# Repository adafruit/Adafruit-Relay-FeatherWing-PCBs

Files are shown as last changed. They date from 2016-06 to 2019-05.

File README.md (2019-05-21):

## Adafruit Relay FeatherWing PCBs
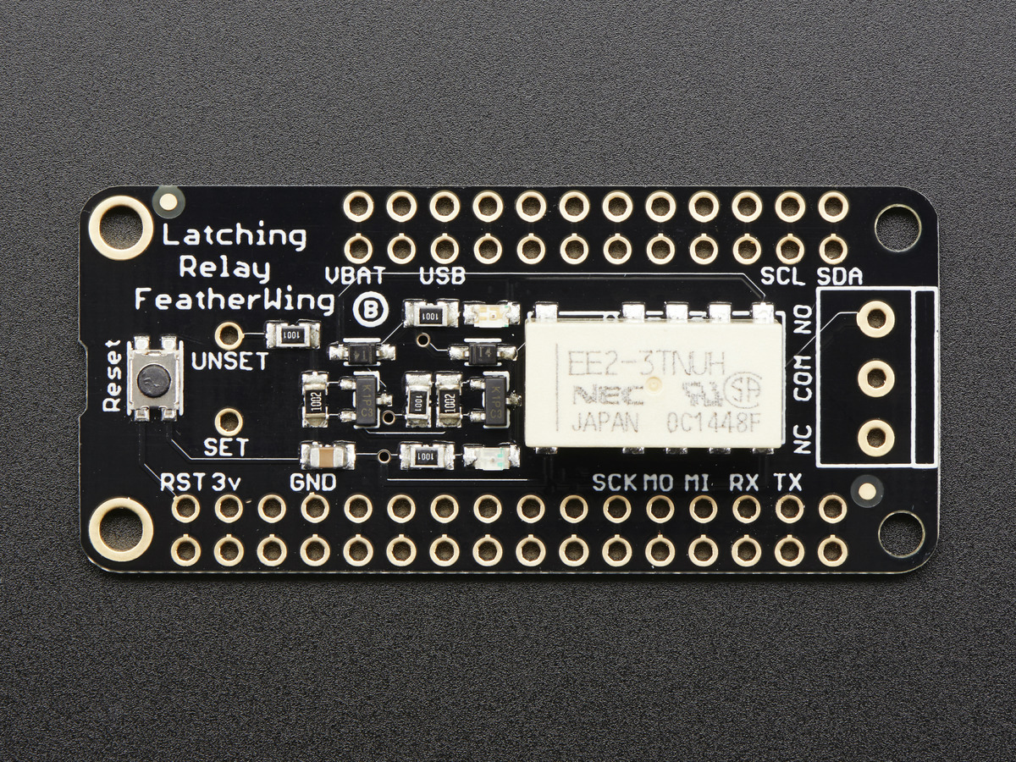
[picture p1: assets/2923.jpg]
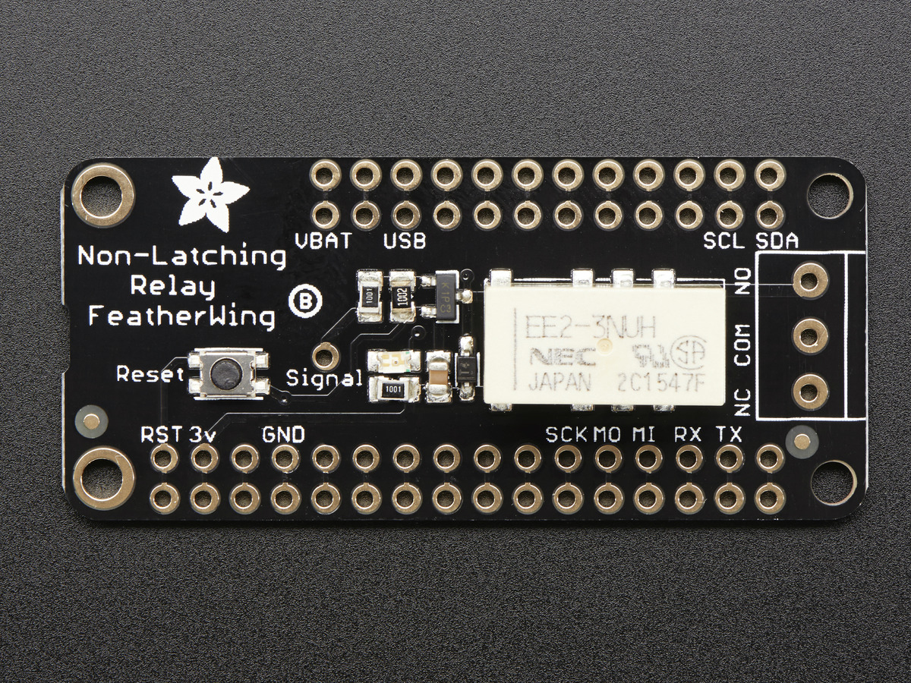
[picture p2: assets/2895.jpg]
&nbsp; <br />
Click to purchase from the Adafruit Shop:
- [Latching Mini Relay FeatherWing](https://www.adafruit.com/product/2923)
- [Non-Latching Mini Relay FeatherWing](https://www.adafruit.com/product/2895)

The are two 'flavors' of these FeatherWings, one is the Latching relay, requires two pins, a SET and UNSET and instead of keeping the SET pin high, you only have to pulse each pin high for 10ms to latch the relay open or closed. You need two pins but save power. Note, if power is lost, the relay will stay in the last setting.

The other type of relay FeatherWing is the simple Non-Latching relay, it requires only a single signal pin.

Both FeatherWings use the same family of relay. You can switch up to 2A of resistive current at 30VDC or ~40VAC or lower. At 110VDC you can switch up to 0.3A, at 120VAC up to 0.5A, and at 250VAC you can switch up to 0.6A. Check the datasheet for the relay for the exact switching capacity, and of course, for reactive/inductive loads you will need to derate. This isn't a relay you can use to turn on and off your washer/dryer, stick to 60W or less. For up to 1200W devices, check out our Power Featherwing which can handle up to 10A!

For more details, check out the product pages at
- https://www.adafruit.com/products/2923
- https://www.adafruit.com/products/2895

This is the PCB files for the Adafruit Relay FeatherWings. The format is EagleCAD schematic and board layout

### License

Adafruit invests time and resources providing this open source design, please support Adafruit and open-source hardware by purchasing products from [Adafruit](https://www.adafruit.com)!

All text above must be included in any redistribution

Designed by Limor Fried/Ladyada for Adafruit Industries.
Creative Commons Attribution/Share-Alike, all text above must be included in any redistribution. 
See license.txt for additional information.

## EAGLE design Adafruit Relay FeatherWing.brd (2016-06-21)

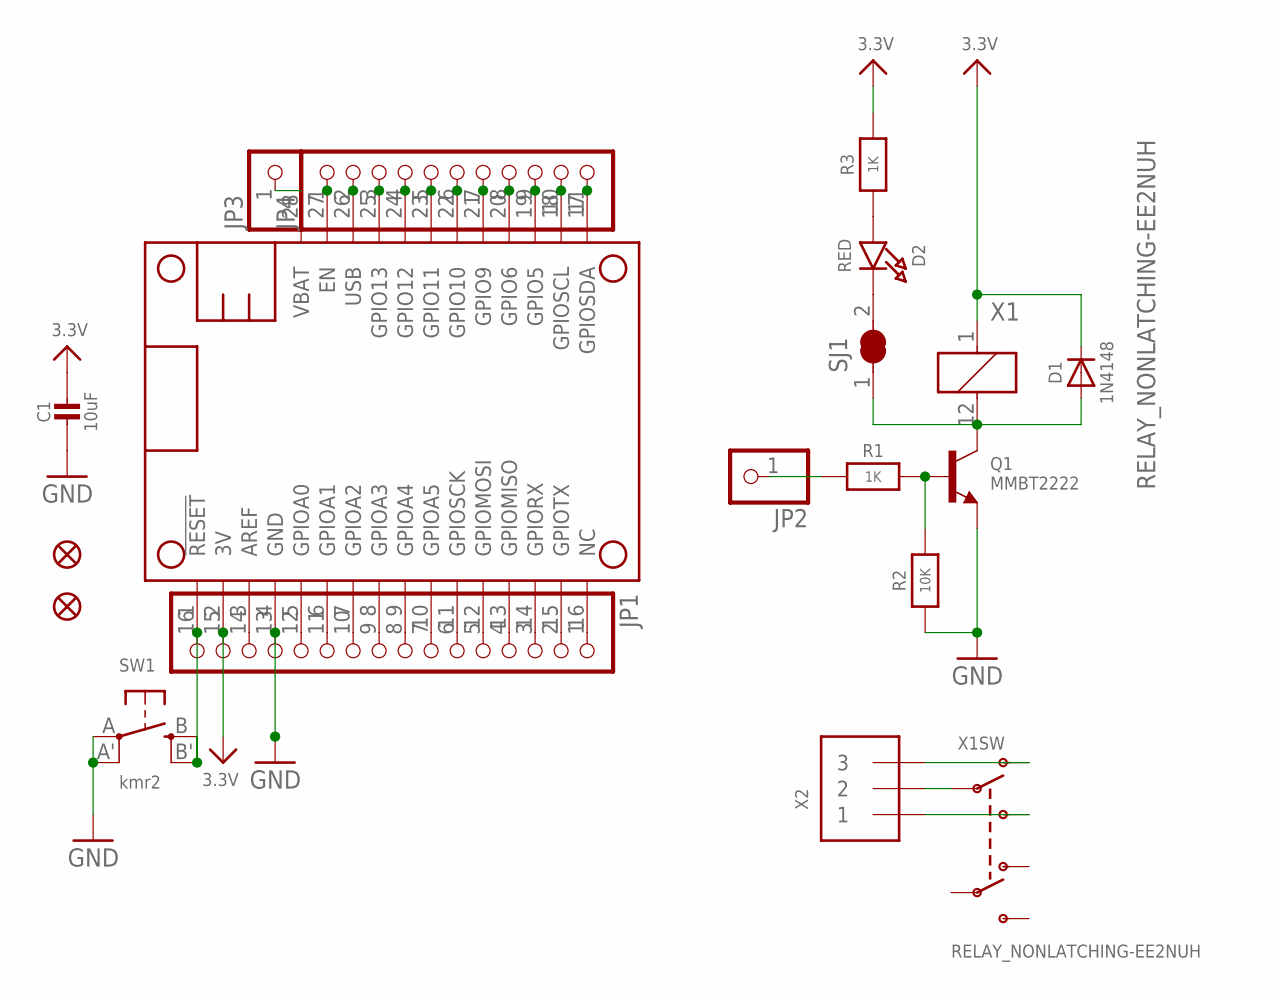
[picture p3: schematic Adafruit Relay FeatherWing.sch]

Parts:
C1: 10uF; 0805-NO
D1: 1N4148; SOD-323
D2: RED; CHIPLED_0805_NOOUTLINE
FID2, FID3: FIDUCIAL""; FIDUCIAL_1MM
JP1: HEADER-1X16ROUND; 1X16_ROUND
JP2, JP3: HEADER-1X1ROUND; 1X01_ROUND
JP4: HEADER-1X11; 1X11_ROUND
MS1: MICROSHIELD
Q1: MMBT2222; SOT23-R
R1, R3: 1K; 0805-NO
R2: 10K; 0805-NO
SJ1: SOLDERJUMPER_CLOSED; SOLDERJUMPER_CLOSEDWIRE
SW1: kmr2; BTN_KMR2_4.6X2.8
X1: RELAY_NONLATCHING-EE2NUH; RELAY_EE2_NOLATCH
X2: TERMBLOCK_1X3; TERMBLOCK_1X3-3.5MM

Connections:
3.3V: C1.1, D1.C, JP1.15, MS1.2 (3V), R3.2, X1.1
COM1: X1.9 (P1), X2.2
GND: C1.2, JP1.13, MS1.4 (GND), Q1.2 (E), R2.1, SW1.A, SW1.A' (P1)
unnamed: D1.A, Q1.3 (C), SJ1.1, X1.12 (2)
unnamed: JP1.1, MS1.16 (NC)
unnamed: JP1.2, MS1.15 (GPIOTX)
unnamed: JP1.3, MS1.14 (GPIORX)
unnamed: JP1.4, MS1.13 (GPIOMISO)
unnamed: JP1.5, MS1.12 (GPIOMOSI)
unnamed: JP1.6, MS1.11 (GPIOSCK)
unnamed: JP1.7, MS1.10 (GPIOA5)
unnamed: JP1.8, MS1.9 (GPIOA4)
unnamed: JP1.9, MS1.8 (GPIOA3)
unnamed: JP1.10, MS1.7 (GPIOA2)
unnamed: JP1.11, MS1.6 (GPIOA1)
unnamed: JP1.12, MS1.5 (GPIOA0)
unnamed: JP4.1, MS1.27 (EN)
unnamed: JP4.3, MS1.25 (GPIO13)
unnamed: JP4.4, MS1.24 (GPIO12)
unnamed: JP4.5, MS1.23 (GPIO11)
unnamed: JP4.6, MS1.22 (GPIO10)
unnamed: JP4.7, MS1.21 (GPIO9)
unnamed: JP4.8, MS1.20 (GPIO6)
unnamed: JP4.9, MS1.19 (GPIO5)
unnamed: Q1.1 (B), R1.2, R2.2
unnamed: JP1.14, MS1.3 (AREF)
unnamed: JP2.1, R1.1
unnamed: D2.C, SJ1.2
unnamed: D2.A, R3.1
unnamed: X1.10 (O1), X2.3
NO1: X1.8 (S1), X2.1
RESET: JP1.16, MS1.1 (!RESET), SW1.B (S), SW1.B' (S1)
SCL: JP4.10, MS1.18 (GPIOSCL)
SDA: JP4.11, MS1.17 (GPIOSDA)
USB: JP4.2, MS1.26 (USB)
VBAT: JP3.1, MS1.28 (VBAT)

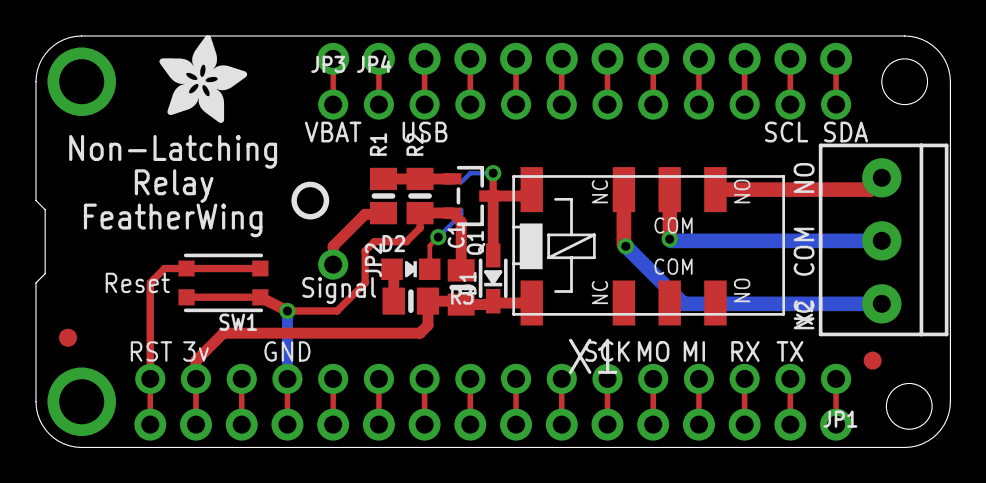
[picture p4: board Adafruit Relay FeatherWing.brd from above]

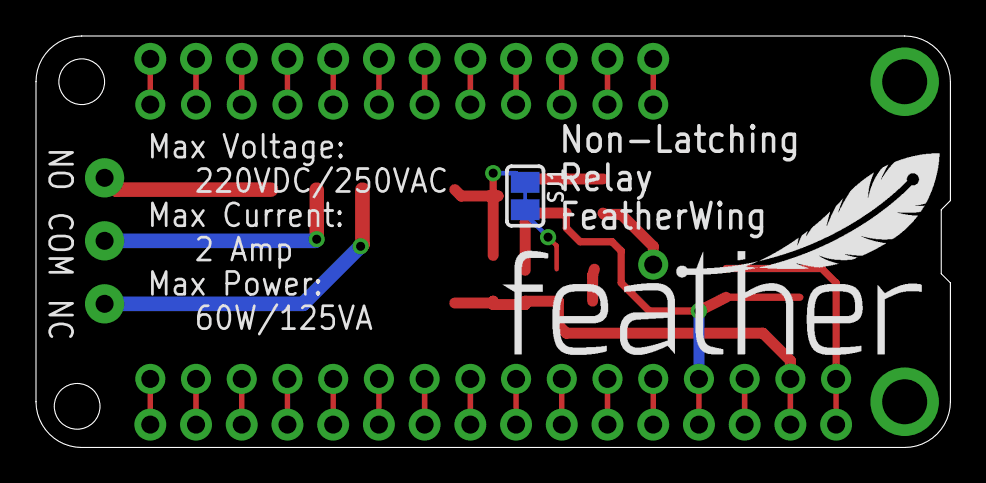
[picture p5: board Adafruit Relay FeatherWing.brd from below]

Board: 2 copper layers, 50.8 x 22.9 mm, 21 parts (2 on the bottom side), 36 nets.

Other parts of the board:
U$5: PCBFEAT-REV-040
U$6: FEATHERLOGO
U$7: ADAFRUIT_5MM

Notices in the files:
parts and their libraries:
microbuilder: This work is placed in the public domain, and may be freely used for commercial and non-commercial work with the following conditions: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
